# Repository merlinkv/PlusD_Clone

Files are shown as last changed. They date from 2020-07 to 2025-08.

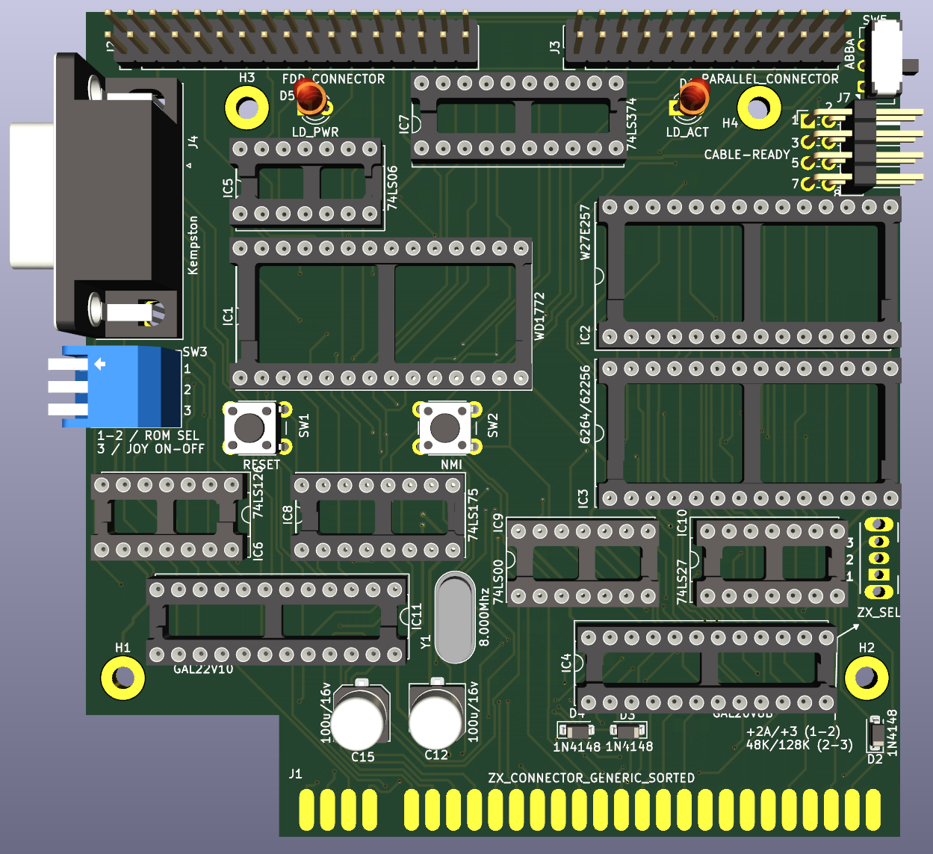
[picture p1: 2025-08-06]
ZX_PlusD_Clone_1_7_Front.jpg

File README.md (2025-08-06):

# PlusD Clone

<br />This work is licensed under a <a rel="license" href="http://creativecommons.org/licenses/by-nc-sa/4.0/">Creative Commons Attribution-NonCommercial-ShareAlike 4.0 International License</a>.

* If you remix, transform, or build upon the material, you must distribute your contributions under the same license as the original.
* You may not use the material for commercial purposes.
* You must give appropriate credit, provide a link to the license, and indicate if changes were made. You may do so in any reasonable manner, but not in any way that suggests the licensor endorses you or your use.

This interface is based on the original PlusD (+D) interface from Miles Gordon Technology and the clone designs by @Pachuquin & @alvaroalea.

# ATTENTION

This project was made for the retro community and not for commercial purposes. So only retro hardware forums and individual people can build this project.

THE SALE OF ANY PART OF THIS PROJECT ON EBAY OR OTHER AUCTION SITES IS PROHIBITED

# Note

I take no responsibiltiy for any damage to any equipment that results from the use of this board. USE AT YOUR OWN RISK!

# Original short description

The PlusD (or +D) was a floppy disk and printer interface for the Sinclair ZX Spectrum home computer, developed as a successor to Miles Gordon Technology's earlier product, the DISCiPLE. It runs the GDOS or Uni-Dos operating systems and you can connect up to two 3.5" floppy drives.

The PlusD will allow you to save all your games and serious software to disc at the touch of a button for reloading at any time in the future. With the fastest load and
save times of any disc system available for the Spectrum, the PLUS D will make your computer grow to meet your needs today and tomorrow! In the software arena, many
leading companies are now producing software that is specifically tailored to the PLUS D. But don't worry - you don't have to buy new software to use the PLUS D!
And if some of your software is Microdrive compatible, so much the better! The PLUS D will add a new dimension to all your existing software, greatly enhancing all
your own programs as well!

# August 6, 2025 - PlusD Clone 1.7

* Added Fire2 button on Kempston interface. Now you can play games that are ready for two buttons or modified to add this possibility like on some games modded by @mad3001 at the VDR site: [Games with Fire2](https://www.va-de-retro.com/foros/viewtopic.php?t=12277)

- [Interactive BOM](https://htmlpreview.github.io/?https://github.com/merlinkv/PlusD_Clone/blob/master/ZX_PlusD_Clone_1_7.html)

# PlusD Clone 1.6

My ZX PlusD Clone can be used on all ZX Spectrum computers just using a little switch (you don't need a "fixer" for +2A, +2B or +3 models). Also you can select one of the two ROMs included (GDOS & Uni-Dos -up to four ROMs can be used-) and play almost all games with the integrated Kempston Joystick interface.

# July 30, 2021

* Corrected some IC labels on the board.

# November 25, 2020

* The solder pad used to select the floppy drive controller IC has been removed.
The floppy drive controller IC's that can be used are: WD1772-02-00, WD1772-02-02 & VL1772-02PC
* Some minor changes.

# October 16, 2020

* Resistors, capacitors (except the two electrolytics) & diodes now are SMD 1206
* Some minor changes

# September 25, 2020

* In this version the solder pads to select the READY signal has been removed.
* Now you can fin a connector of 4x2 pins to put the jumpers.
     
     * Upper row: Cable selector (AT or Shugart)
     * Bottom row: READY signal selector, REAL or EMU
      
     See attached pictures.

# July 27, 2020

Tested & working 100%
* In this version of the board the IC 7805 has been removed. The interface power is taken from the + 5V line of the expansion bus.

# July 11, 2020

* Corrected footprint of U2 (W27E257)
* Everything seems to be OK. Ordering 5 PCB's to test.

# July 6, 2020

* Added a SPDT switch ON-ON to select between ZX 48K/128K & +2A/+3
* Inversion of Drive 1 and Drive 2 now is made by a DPDT Switch (ABBA)
* Now the IC12 (L7805) can be placed horizontally
* Relocation of LEDS, NMI and RESET pushbuttons and some IC's
* Added three 3M holes (3.5mm) to facilitate the fixation on a case
* Kempston Joystick connector now is horizontal
* Changed the DIP switch for ROM selection and Joystick ON-OFF for a DIP Switch Piano style.
* Electrolytic capacitors are now SMD

# Notes

Two types can be used as the IC for floppy disk controller: WD1772 (versions 02-00 and 02-02) and VL1772-02PC.
Unfortunately, they are difficult to find at reasonable prices.

The advantages of this interface over the original are:

* 4 Banks of ROM, so you can swap between G+Dos and Unidos, selectable by dip-switches
* Included Fixed for +2A/+3, so can be used in any ZX Spectrum, selection by switch
* Kempston Joystick Interface included, can be disable by dip-switch
* Reset Button
* Posibility of use crossed or plain floppy cable, and invert Drive 1 and Drive 2, very usefull if you have a Gotek and a real floppy.

# Links

* https://www.winuaespanol.com/phpbb3/viewtopic.php?p=7182#p7182
* https://github.com/alvaroalea/plusD-clone
* https://www.va-de-retro.com/foros/viewtopic.php?f=63&t=5561

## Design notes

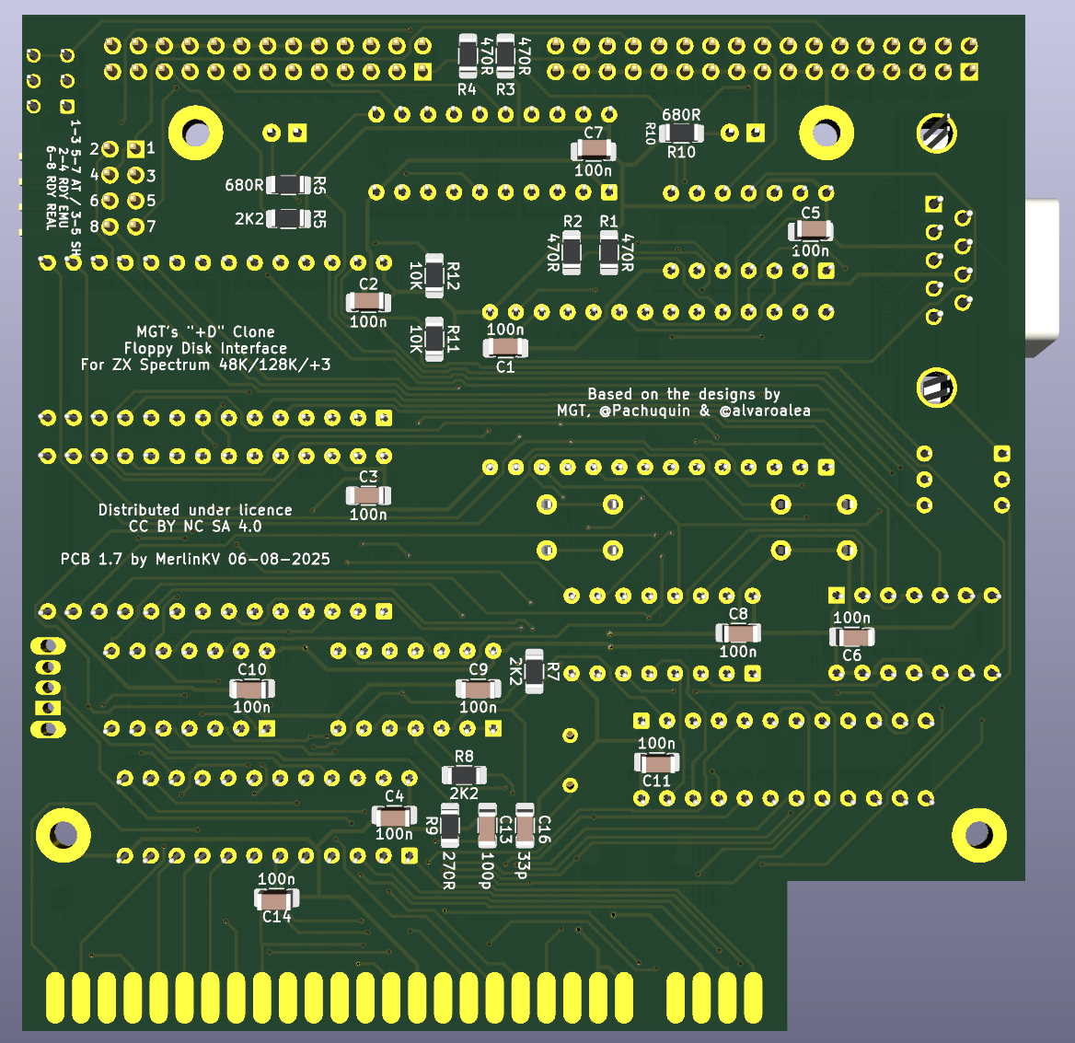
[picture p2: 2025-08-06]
ZX_PlusD_Clone_1_7_Back.jpg

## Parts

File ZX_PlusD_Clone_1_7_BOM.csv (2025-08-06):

Id | Designator | Footprint | Quantity | Designation | Supplier and ref
1 | J4 | DSUB-9_Male_Horizontal_P2.77x2.84mm_EdgePinOffset4.94mm_Housed_MountingHolesOffset7.48mm | 1 | Kempston
2 | SW4 | SW_CuK_OS102011MA1QN1_SPDT_Angled | 1 | ZX_SEL
3 | IC10 | DIP-14_W7.62mm_Socket | 1 | 74LS27
4 | IC9 | DIP-14_W7.62mm_Socket | 1 | 74LS00
5 | IC6 | DIP-14_W7.62mm_Socket | 1 | 74LS126
6 | D5 | LED_D3.0mm | 1 | LD_PWR
7 | SW3 | SW_DIP_SPSTx03_Piano_10.8x9.18mm_W7.62mm_P2.54mm | 1 | ROMSEL_JOY
8 | Y1 | Crystal_HC18-U_Vertical | 1 | 8.000Mhz
9 | D1 | LED_D3.0mm | 1 | LD_ACT
10 | IC5 | DIP-14_W7.62mm_Socket | 1 | 74LS06
11 | J3 | PinHeader_2x13_P2.54mm_Vertical | 1 | PARALLEL_CONNECTOR
12 | J1 | ZX_CONNECTOR_GENERIC_SORTED | 1 | ZX_CONNECTOR_GENERIC_SORTED
13 | IC1 | DIP-28_W15.24mm_Socket | 1 | WD1772
14 | IC3 | DIP-28_W15.24mm_Socket | 1 | 6264/62256
15 | IC4 | DIP-24_W7.62mm_Socket | 1 | GAL20V8B
16 | IC8 | DIP-16_W7.62mm_Socket | 1 | 74LS175
17 | IC7 | DIP-20_W7.62mm_Socket | 1 | 74LS374
18 | SW1 | SW_PUSH_6mm | 1 | RESET
19 | SW2 | SW_PUSH_6mm | 1 | NMI
20 | IC11 | DIP-24_W7.62mm_Socket | 1 | GAL22V10
21 | IC2 | DIP-28_W15.24mm_Socket | 1 | W27E257
22 | SW5 | SW_CK_JS202011AQN_DPDT_Angled | 1 | ABBA
23 | C15,C12 | C_Elec_6.3x5.4 | 2 | 100u/16v
24 | J7 | PinHeader_2x04_P2.54mm_Horizontal | 1 | CABLE-READY
25 | D2,D3,D4 | D_SOD-123 | 3 | 1N4148
26 | J2 | PinHeader_2x17_P2.54mm_Vertical | 1 | FDD_CONNECTOR
27 | C16 | C_1206_3216Metric_Pad1.33x1.80mm_HandSolder | 1 | 33p
28 | R9 | R_1206_3216Metric_Pad1.30x1.75mm_HandSolder | 1 | 270R
29 | R6,R10 | R_1206_3216Metric_Pad1.30x1.75mm_HandSolder | 2 | 680R
30 | R12,R11 | R_1206_3216Metric_Pad1.30x1.75mm_HandSolder | 2 | 10K
31 | R7,R8,R5 | R_1206_3216Metric_Pad1.30x1.75mm_HandSolder | 3 | 2K2
32 | C13 | C_1206_3216Metric_Pad1.33x1.80mm_HandSolder | 1 | 100p
33 | C14,C1,C4,C5,C6,C7,C8,C9,C10,C11,C2,C3 | C_1206_3216Metric_Pad1.33x1.80mm_HandSolder | 12 | 100n
34 | R1,R2,R4,R3 | R_1206_3216Metric_Pad1.30x1.75mm_HandSolder | 4 | 470R

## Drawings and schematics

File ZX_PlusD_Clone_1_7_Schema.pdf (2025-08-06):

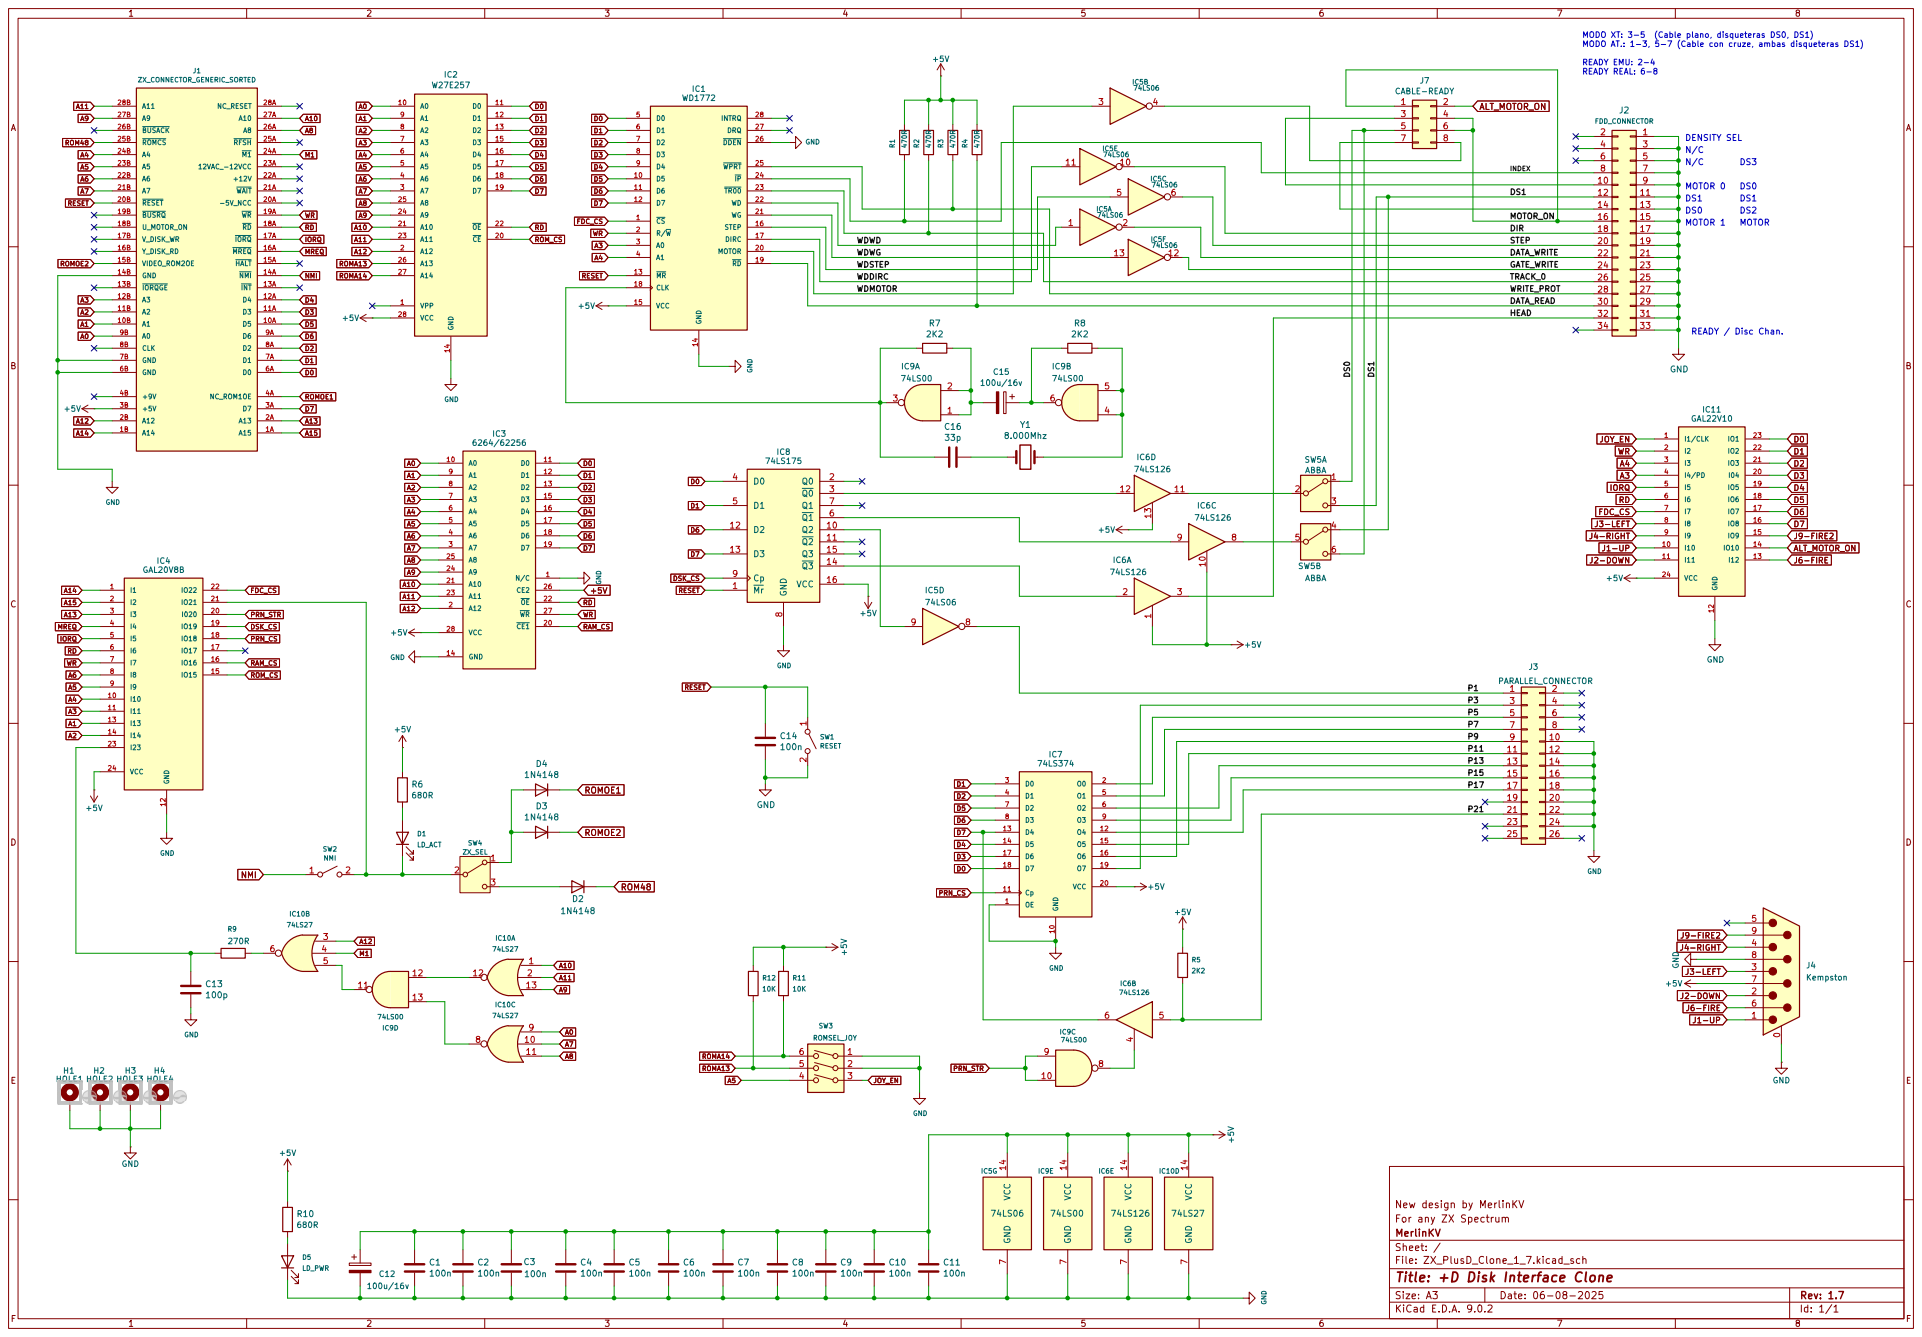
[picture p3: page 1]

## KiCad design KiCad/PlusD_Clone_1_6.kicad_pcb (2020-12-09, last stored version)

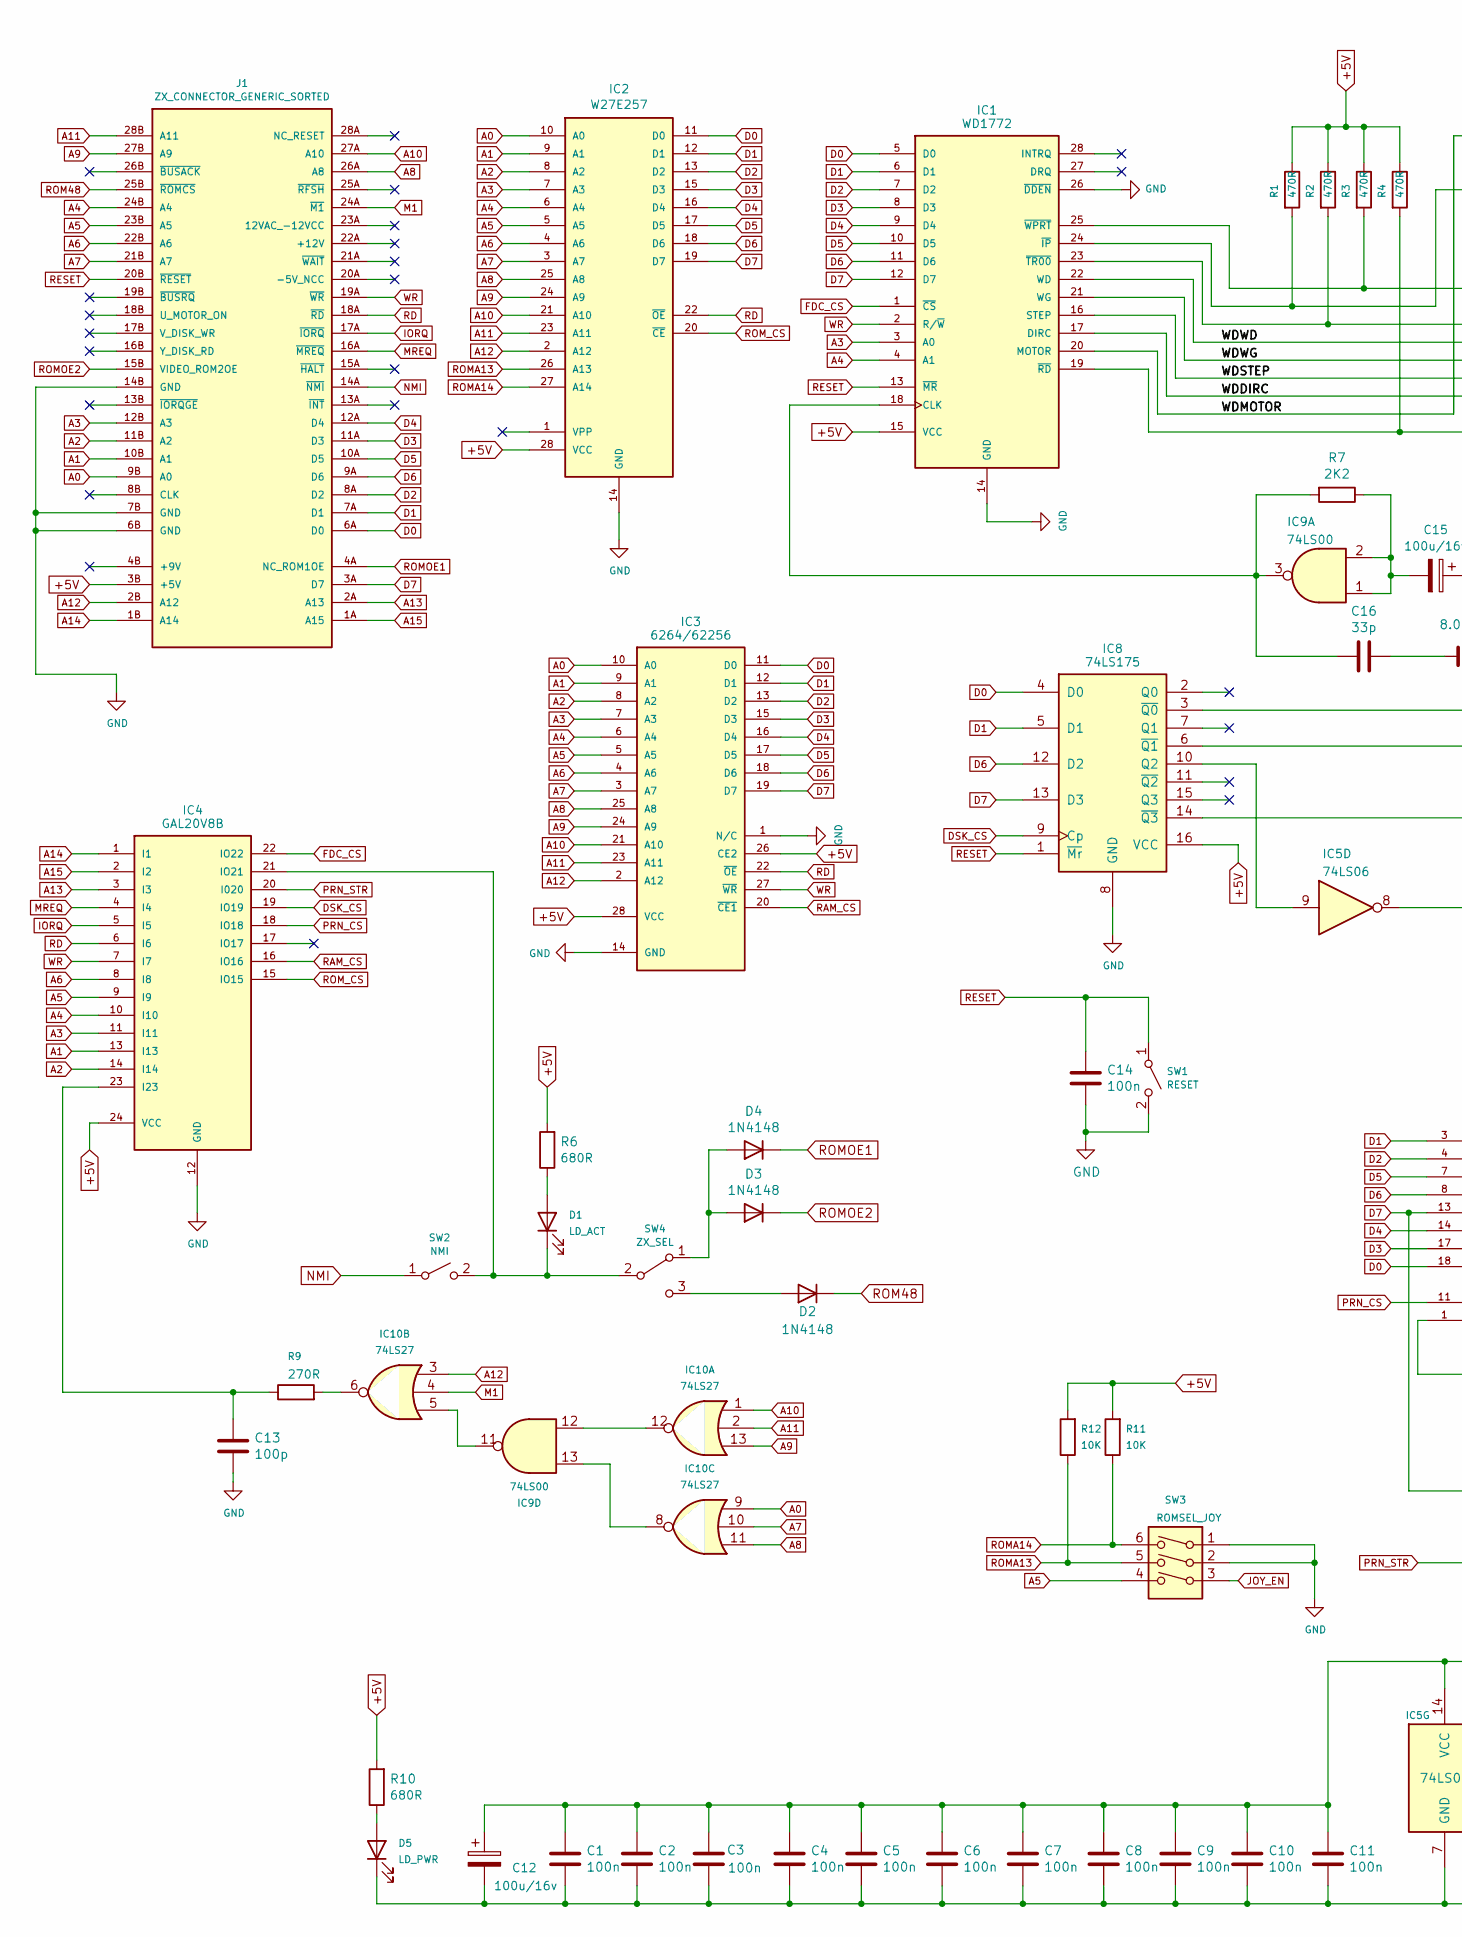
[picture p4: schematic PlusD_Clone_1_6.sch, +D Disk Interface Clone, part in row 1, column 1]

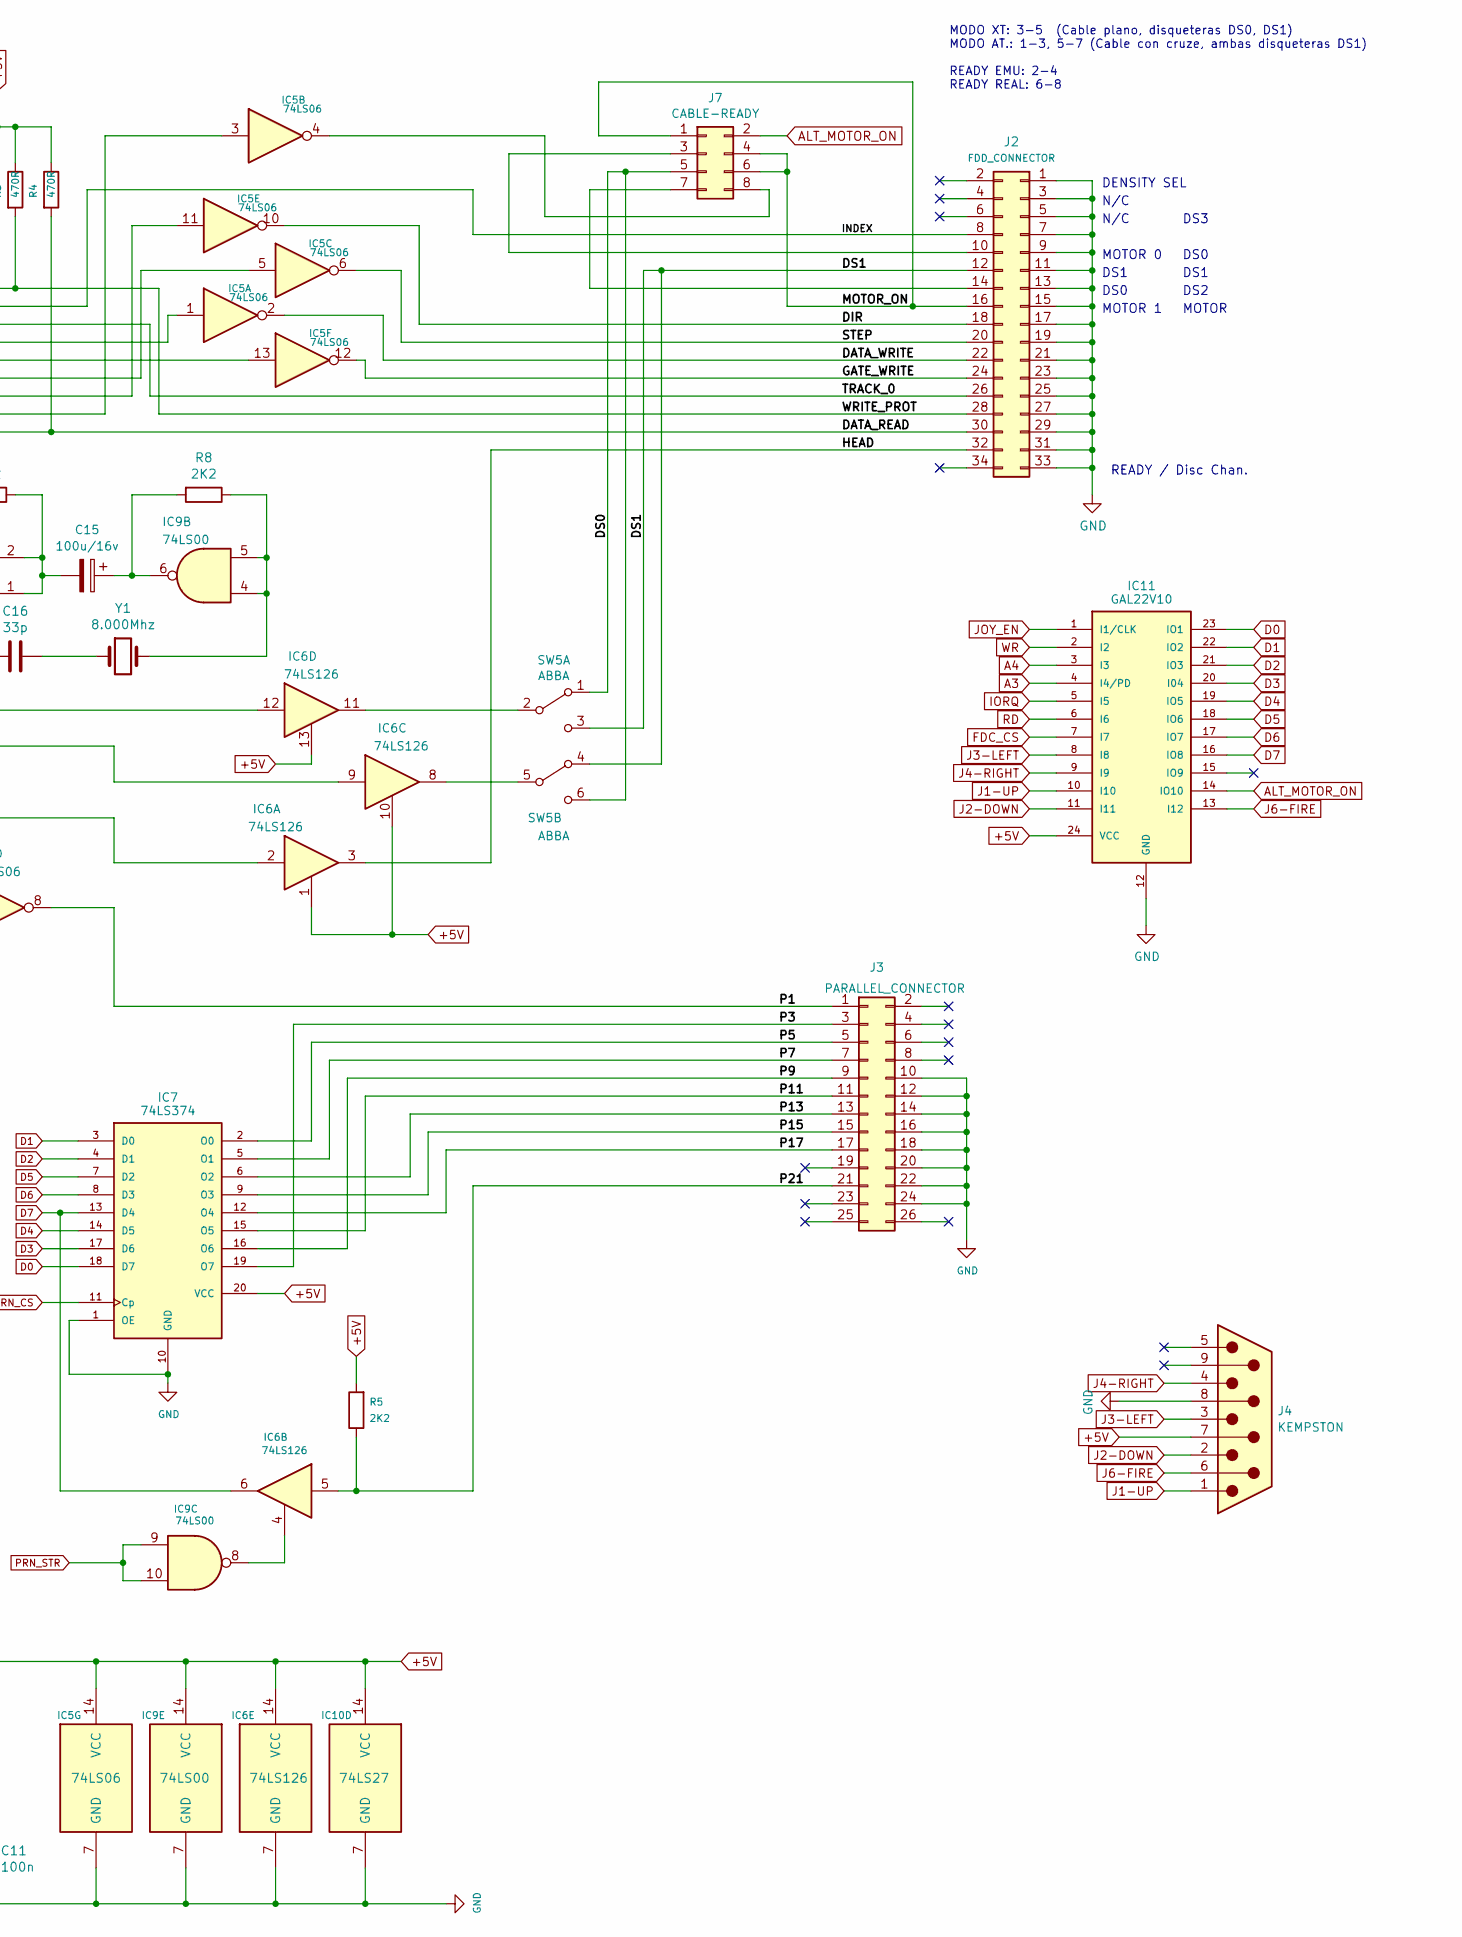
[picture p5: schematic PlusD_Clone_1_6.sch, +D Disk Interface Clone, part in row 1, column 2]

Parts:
C1, C2, C3, C4, C5, C6, C7, C8, C9, C10, C11, C14: 100n; C_1206_3216Metric_Pad1.42x1.75mm_HandSolder
C12, C15: 100u/16v; C_Elec_6.3x5.4
C13: 100p; C_1206_3216Metric_Pad1.42x1.75mm_HandSolder
C16: 33p; C_1206_3216Metric_Pad1.42x1.75mm_HandSolder
D1: LD_ACT; LED_D5.0mm
D2, D3, D4: 1N4148; D_SOD-123
D5: LD_PWR; LED_D5.0mm
IC1: WD1772; DIP-28_W15.24mm_Socket_LongPads
IC2: W27E257; DIP-28_W15.24mm_Socket_LongPads
IC3: 6264/62256; DIP-28_W15.24mm_Socket_LongPads
IC4: GAL20V8B; DIP-24_W7.62mm_Socket_LongPads
IC5: 74LS06; DIP-14_W7.62mm_Socket_LongPads
IC6: 74LS126; DIP-14_W7.62mm_Socket_LongPads
IC7: 74LS374; DIP-20_W7.62mm_Socket_LongPads
IC8: 74LS175; DIP-16_W7.62mm_Socket_LongPads
IC9: 74LS00; DIP-14_W7.62mm_Socket_LongPads
IC10: 74LS27; DIP-14_W7.62mm_Socket_LongPads
IC11: GAL22V10; DIP-24_W7.62mm_Socket_LongPads
J1: ZX_CONNECTOR_GENERIC_SORTED
J2: FDD_CONNECTOR; PinHeader_2x17_P2.54mm_Vertical
J3: PARALLEL_CONNECTOR; PinHeader_2x13_P2.54mm_Vertical
J4: KEMPSTON; DSUB-9_Male_Horizontal_P2.77x2.84mm_EdgePinOffset4.94mm_Hou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
J7: CABLE-READY; PinHeader_2x04_P2.54mm_Horizontal
R1, R2, R3, R4: 470R; R_1206_3216Metric_Pad1.42x1.75mm_HandSolder
R5, R7, R8: 2K2; R_1206_3216Metric_Pad1.42x1.75mm_HandSolder
R6, R10: 680R; R_1206_3216Metric_Pad1.42x1.75mm_HandSolder
R9: 270R; R_1206_3216Metric_Pad1.42x1.75mm_HandSolder
R11, R12: 10K; R_1206_3216Metric_Pad1.42x1.75mm_HandSolder
SW1: RESET; SW_PUSH_6mm
SW2: NMI; SW_PUSH_6mm
SW3: ROMSEL_JOY; SW_DIP_SPSTx03_Piano_10.8x9.18mm_W7.62mm_P2.54mm
SW4: ZX_SEL; SW_CuK_OS102011MA1QN1_SPDT_Angled
SW5: ABBA; SW_CuK_JS202011AQN_DPDT_Angled
Y1: 8.000Mhz; Crystal_HC18-U_Vertical

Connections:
+5V: C1.2, C2.2, C3.2, C4.2, C5.2, C6.2, C7.2, C8.2, C9.2, C10.2, C11.2, C12.1, IC1.15 (VCC), IC2.28 (VCC), IC3.26 (CE2), IC3.28 (VCC), IC4.24 (VCC), IC5.14 (VCC), IC6.1, IC6.10, IC6.13, IC6.14 (VCC), IC7.20 (VCC), IC8.16 (VCC), IC9.14 (VCC), IC10.14 (VCC), IC11.24 (VCC), J1.3B (+5V), J4.7, R1.1, R2.1, R3.1, R4.1, R5.2, R6.2, R10.2, R11.2, R12.2
/DATA_READ: IC1.19 (~RD), J2.30, R4.2
/DATA_WRITE: IC5.2, J2.22
/DIR: IC5.10, J2.18
/DS0: J7.5, SW5.1 (A), SW5.6 (C)
/DS1: J2.12, SW5.3 (C), SW5.4 (A)
/GATE_WRITE: IC5.12, J2.24
/HEAD: IC6.3, J2.32
/INDEX: IC1.24 (~IP), J2.8, R1.2
/MOTOR_ON: J2.16, J7.1, J7.4, J7.6
/P1: IC5.8, J3.1
/P3: IC7.19 (O7), J3.3
/P5: IC7.2 (O0), J3.5
/P7: IC7.5 (O1), J3.7
/P9: IC7.16 (O6), J3.9
/P11: IC7.15 (O5), J3.11
/P13: IC7.6 (O2), J3.13
/P15: IC7.9 (O3), J3.15
/P17: IC7.12 (O4), J3.17
/P21: IC6.5, J3.21, R5.1
/STEP: IC5.6, J2.20
/TRACK_0: IC1.23 (~TR00), J2.26, R2.2
/WDDIRC: IC1.17 (DIRC), IC5.11
/WDMOTOR: IC1.20 (MOTOR), IC5.3
/WDSTEP: IC1.16 (STEP), IC5.5
/WDWD: IC1.22 (WD), IC5.1
/WDWG: IC1.21 (WG), IC5.13
/WRITE_PROT: IC1.25 (~WPRT), J2.28, R3.2
A0: IC2.10 (A0), IC3.10 (A0), IC10.9, J1.9B (A0)
A1: IC2.9 (A1), IC3.9 (A1), IC4.13 (I13), J1.10B (A1)
A2: IC2.8 (A2), IC3.8 (A2), IC4.14 (I14), J1.11B (A2)
A3: IC1.3 (A0), IC2.7 (A3), IC3.7 (A3), IC4.11 (I11), IC11.4 (I4/PD), J1.12B (A3)
A4: IC1.4 (A1), IC2.6 (A4), IC3.6 (A4), IC4.10 (I10), IC11.3 (I3), J1.24B (A4)
A5: IC2.5 (A5), IC3.5 (A5), IC4.9 (I9), J1.23B (A5), SW3.4
A6: IC2.4 (A6), IC3.4 (A6), IC4.8 (I8), J1.22B (A6)
A7: IC2.3 (A7), IC3.3 (A7), IC10.10, J1.21B (A7)
A8: IC2.25 (A8), IC3.25 (A8), IC10.11, J1.26A (A8)
A9: IC2.24 (A9), IC3.24 (A9), IC10.13, J1.27B (A9)
A10: IC2.21 (A10), IC3.21 (A10), IC10.1, J1.27A (A10)
A11: IC2.23 (A11), IC3.23 (A11), IC10.2, J1.28B (A11)
A12: IC2.2 (A12), IC3.2 (A12), IC10.3, J1.2B (A12)
A13: IC4.3 (I3), J1.2A (A13)
A14: IC4.1 (I1), J1.1B (A14)
A15: IC4.2 (I2), J1.1A (A15)
ALT_MOTOR_ON: IC11.14 (IO10), J7.2
D0: IC1.5 (D0), IC2.11 (D0), IC3.11 (D0), IC7.18 (D7), IC8.4 (D0), IC11.23 (IO1), J1.6A (D0)
D1: IC1.6 (D1), IC2.12 (D1), IC3.12 (D1), IC7.3 (D0), IC8.5 (D1), IC11.22 (IO2), J1.7A (D1)
D2: IC1.7 (D2), IC2.13 (D2), IC3.13 (D2), IC7.4 (D1), IC11.21 (IO3), J1.8A (D2)
D3: IC1.8 (D3), IC2.15 (D3), IC3.15 (D3), IC7.17 (D6), IC11.20 (I04), J1.11A (D3)
D4: IC1.9 (D4), IC2.16 (D4), IC3.16 (D4), IC7.14 (D5), IC11.19 (IO5), J1.12A (D4)
D5: IC1.10 (D5), IC2.17 (D5), IC3.17 (D5), IC7.7 (D2), IC11.18 (IO6), J1.10A (D5)
D6: IC1.11 (D6), IC2.18 (D6), IC3.18 (D6), IC7.8 (D3), IC8.12 (D2), IC11.17 (IO7), J1.9A (D6)
D7: IC1.12 (D7), IC2.19 (D7), IC3.19 (D7), IC6.6, IC7.13 (D4), IC8.13 (D3), IC11.16 (IO8), J1.3A (D7)
DSK_CS: IC4.19 (IO19), IC8.9 (Cp)
FDC_CS: IC1.1 (~CS), IC4.22 (IO22), IC11.7 (I7)
GND: C1.1, C2.1, C3.1, C4.1, C5.1, C6.1, C7.1, C8.1, C9.1, C10.1, C11.1, C12.2, C13.1, C14.1, D5.1 (K), IC1.14 (GND), IC1.26 (~DDEN), IC2.14 (GND), IC3.1 (N/C), IC3.14 (GND), IC4.12 (GND), IC5.7 (GND), IC6.7 (GND), IC7.1 (OE), IC7.10 (GND), IC8.8 (GND), IC9.7 (GND), IC10.7 (GND), IC11.12 (GND), J1.6B (GND), J1.7B (GND), J1.14B (GND), J2.1, J2.3, J2.5, J2.7, J2.9, J2.11, J2.13, J2.15, J2.17, J2.19, J2.21, J2.23, J2.25, J2.27, J2.29, J2.31, J2.33, J3.10, J3.12, J3.14, J3.16, J3.18, J3.20, J3.22, J3.24, J4.8, SW1.2 (B), SW3.1, SW3.2
IORQ: IC4.5 (I5), IC11.5 (I5), J1.17A (~IORQ)
J1-UP: IC11.10 (I10), J4.1
J2-DOWN: IC11.11 (I11), J4.2
J3-LEFT: IC11.8 (I8), J4.3
J4-RIGHT: IC11.9 (I9), J4.4
J6-FIRE: IC11.13 (I12), J4.6
JOY_EN: IC11.1 (I1/CLK), SW3.3
M1: IC10.4, J1.24A (~M1)
MREQ: IC4.4 (I4), J1.16A (~MREQ)
NMI: J1.14A (~NMI), SW2.1 (A)
unnamed: C13.2, IC4.23 (I23), R9.1
unnamed: C15.1, IC9.6, R8.2
unnamed: C15.2, IC9.1, IC9.2, R7.1
unnamed: C16.1, Y1.1
unnamed: C16.2, IC1.18 (CLK), IC9.3, R7.2
unnamed: D1.1 (K), IC4.21 (IO21), SW2.2 (B), SW4.2 (B)
unnamed: D1.2 (A), R6.1
unnamed: D2.2 (A), SW4.3 (C)
unnamed: D3.2 (A), D4.2 (A), SW4.1 (A)
unnamed: D5.2 (A), R10.1
unnamed: IC5.4, J7.8
unnamed: IC5.9, IC8.10 (Q2)
unnamed: IC6.2, IC8.14 (~Q3)
unnamed: IC6.4, IC9.8
unnamed: IC6.8, SW5.5 (B)
unnamed: IC6.9, IC8.6 (~Q1)
unnamed: IC6.11, SW5.2 (B)
unnamed: IC6.12, IC8.3 (~Q0)
unnamed: IC9.4, IC9.5, R8.1, Y1.2
unnamed: IC9.11, IC10.5
unnamed: IC10.6, R9.2
unnamed: IC9.13, IC10.8
unnamed: IC9.12, IC10.12
unnamed: J2.10, J7.3
unnamed: J2.14, J7.7
PRN_CS: IC4.18 (IO18), IC7.11 (Cp)
PRN_STR: IC4.20 (I020), IC9.9, IC9.10
RAM_CS: IC3.20 (~CE1), IC4.16 (IO16)
RD: IC2.22 (~OE), IC3.22 (~OE), IC4.6 (I6), IC11.6 (I6), J1.18A (~RD)
RESET: C14.2, IC1.13 (~MR), IC8.1 (~Mr), J1.20B (~RESET), SW1.1 (A)
ROM48: D2.1 (K), J1.25B (~ROMCS)
ROMA13: IC2.26 (A13), R12.1, SW3.5
ROMA14: IC2.27 (A14), R11.1, SW3.6
ROMOE1: D4.1 (K), J1.4A (NC_ROM1OE)
ROMOE2: D3.1 (K), J1.15B (VIDEO_ROM2OE)
ROM_CS: IC2.20 (~CE), IC4.15 (IO15)
WR: IC1.2 (R/~W), IC3.27 (~WR), IC4.7 (I7), IC11.2 (I2), J1.19A (~WR)

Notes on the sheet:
READY / Disc Chan.
DENSITY SEL
N/C
MOTOR 1
DS0
DS1
MOTOR 0
MOTOR
DS2
DS0
DS3
MODO XT: 3-5 (Cable plano, disqueteras DS0, DS1) MODO AT.: 1-3, 5-7 (Cable con cruze, ambas disqueteras DS1) READY EMU: 2-4 READY REAL: 6-8

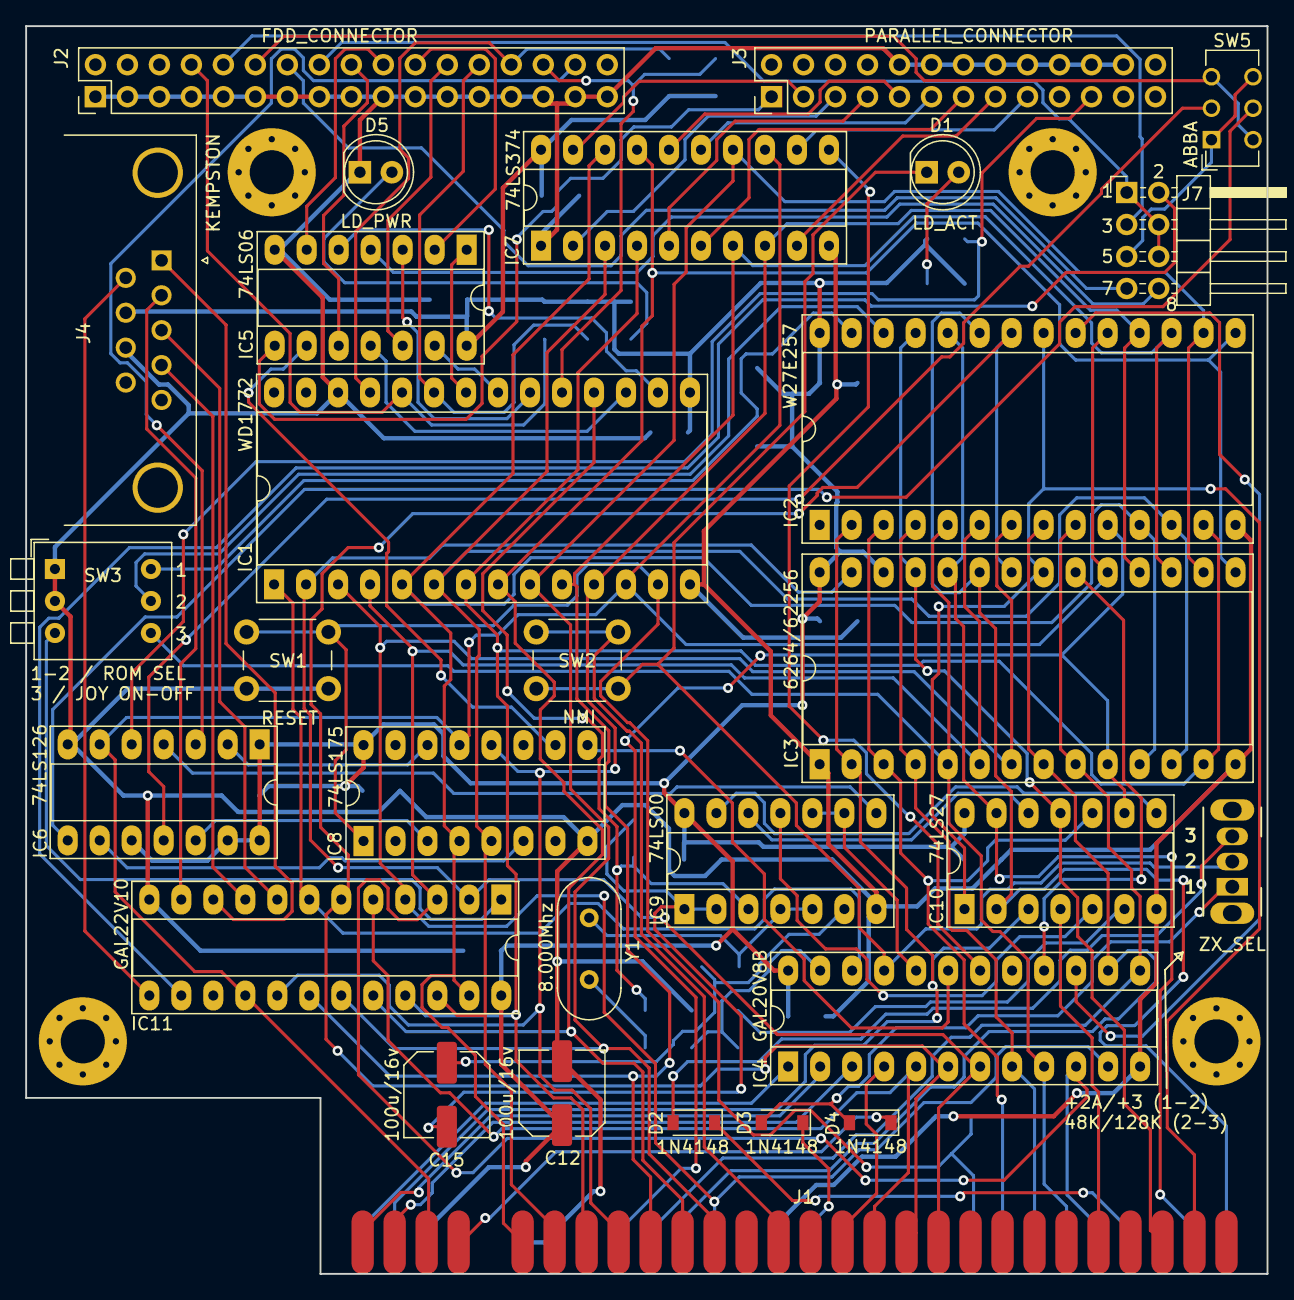
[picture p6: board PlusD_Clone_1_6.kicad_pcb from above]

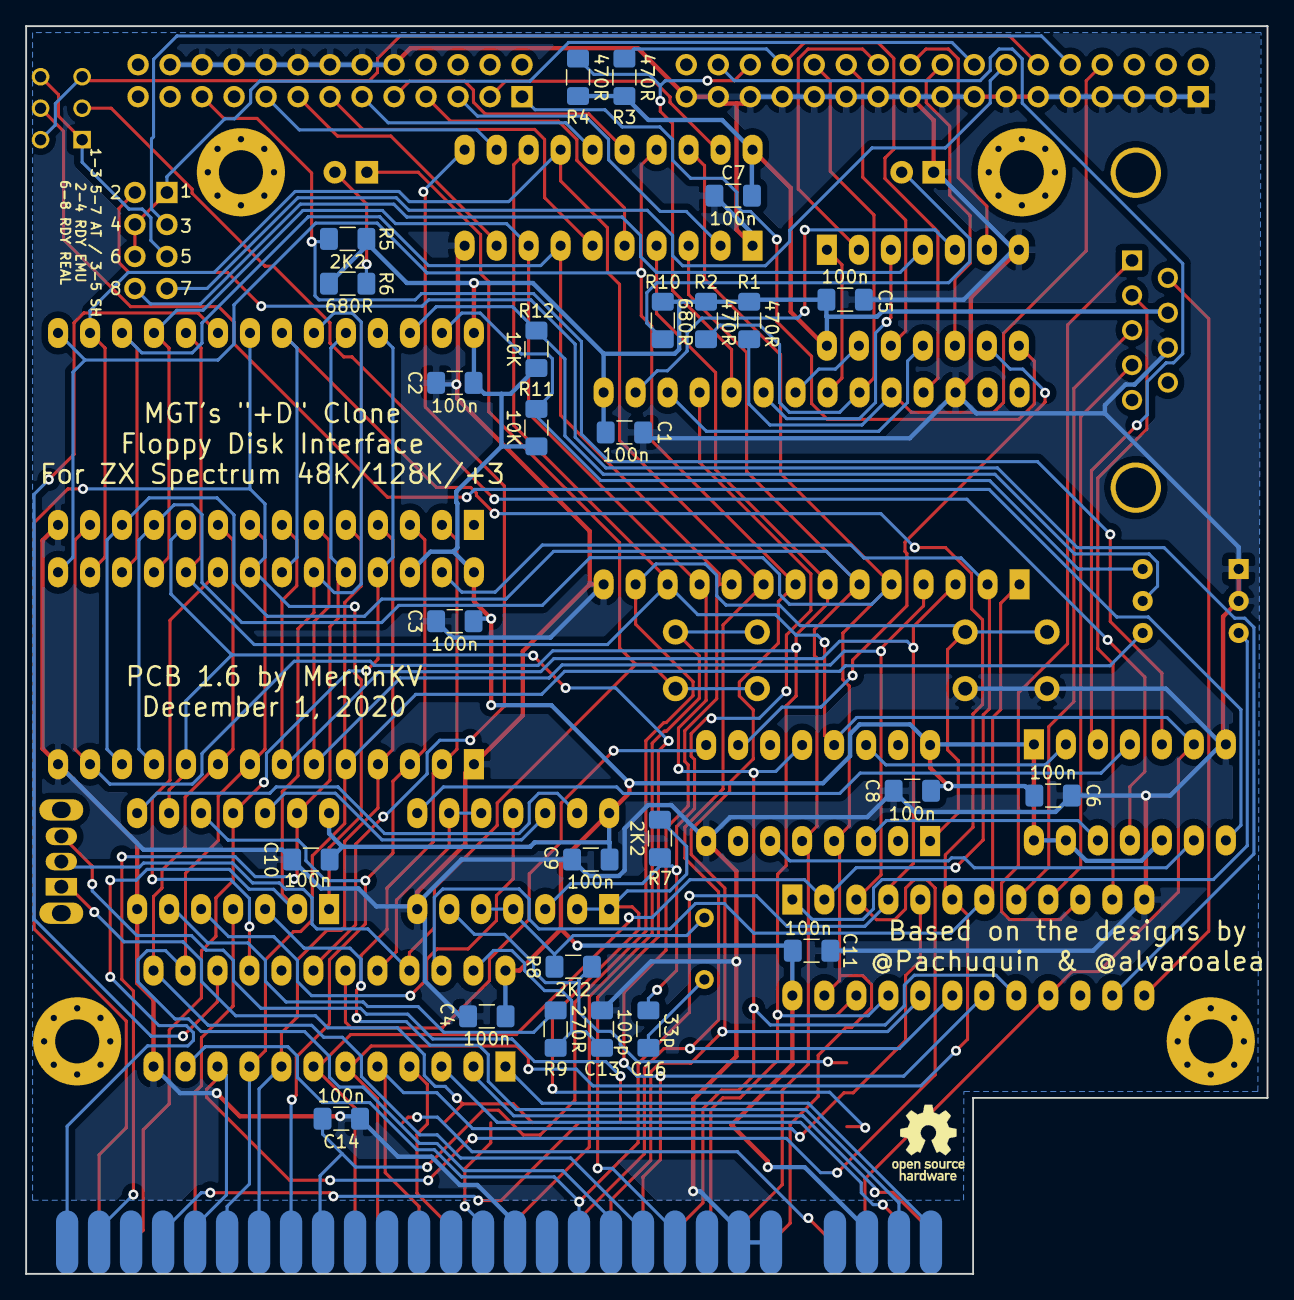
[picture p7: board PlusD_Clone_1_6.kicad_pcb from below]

Board: 2 copper layers, 98.6 x 99.1 mm, 60 parts (27 on the bottom side), 103 nets.

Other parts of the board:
HOLE1, HOLE2, HOLE3, HOLE4: MountingHole_3.5mm_Pad_Via
LOGO1: OSHW-Logo_5.7x6mm_SilkScreen

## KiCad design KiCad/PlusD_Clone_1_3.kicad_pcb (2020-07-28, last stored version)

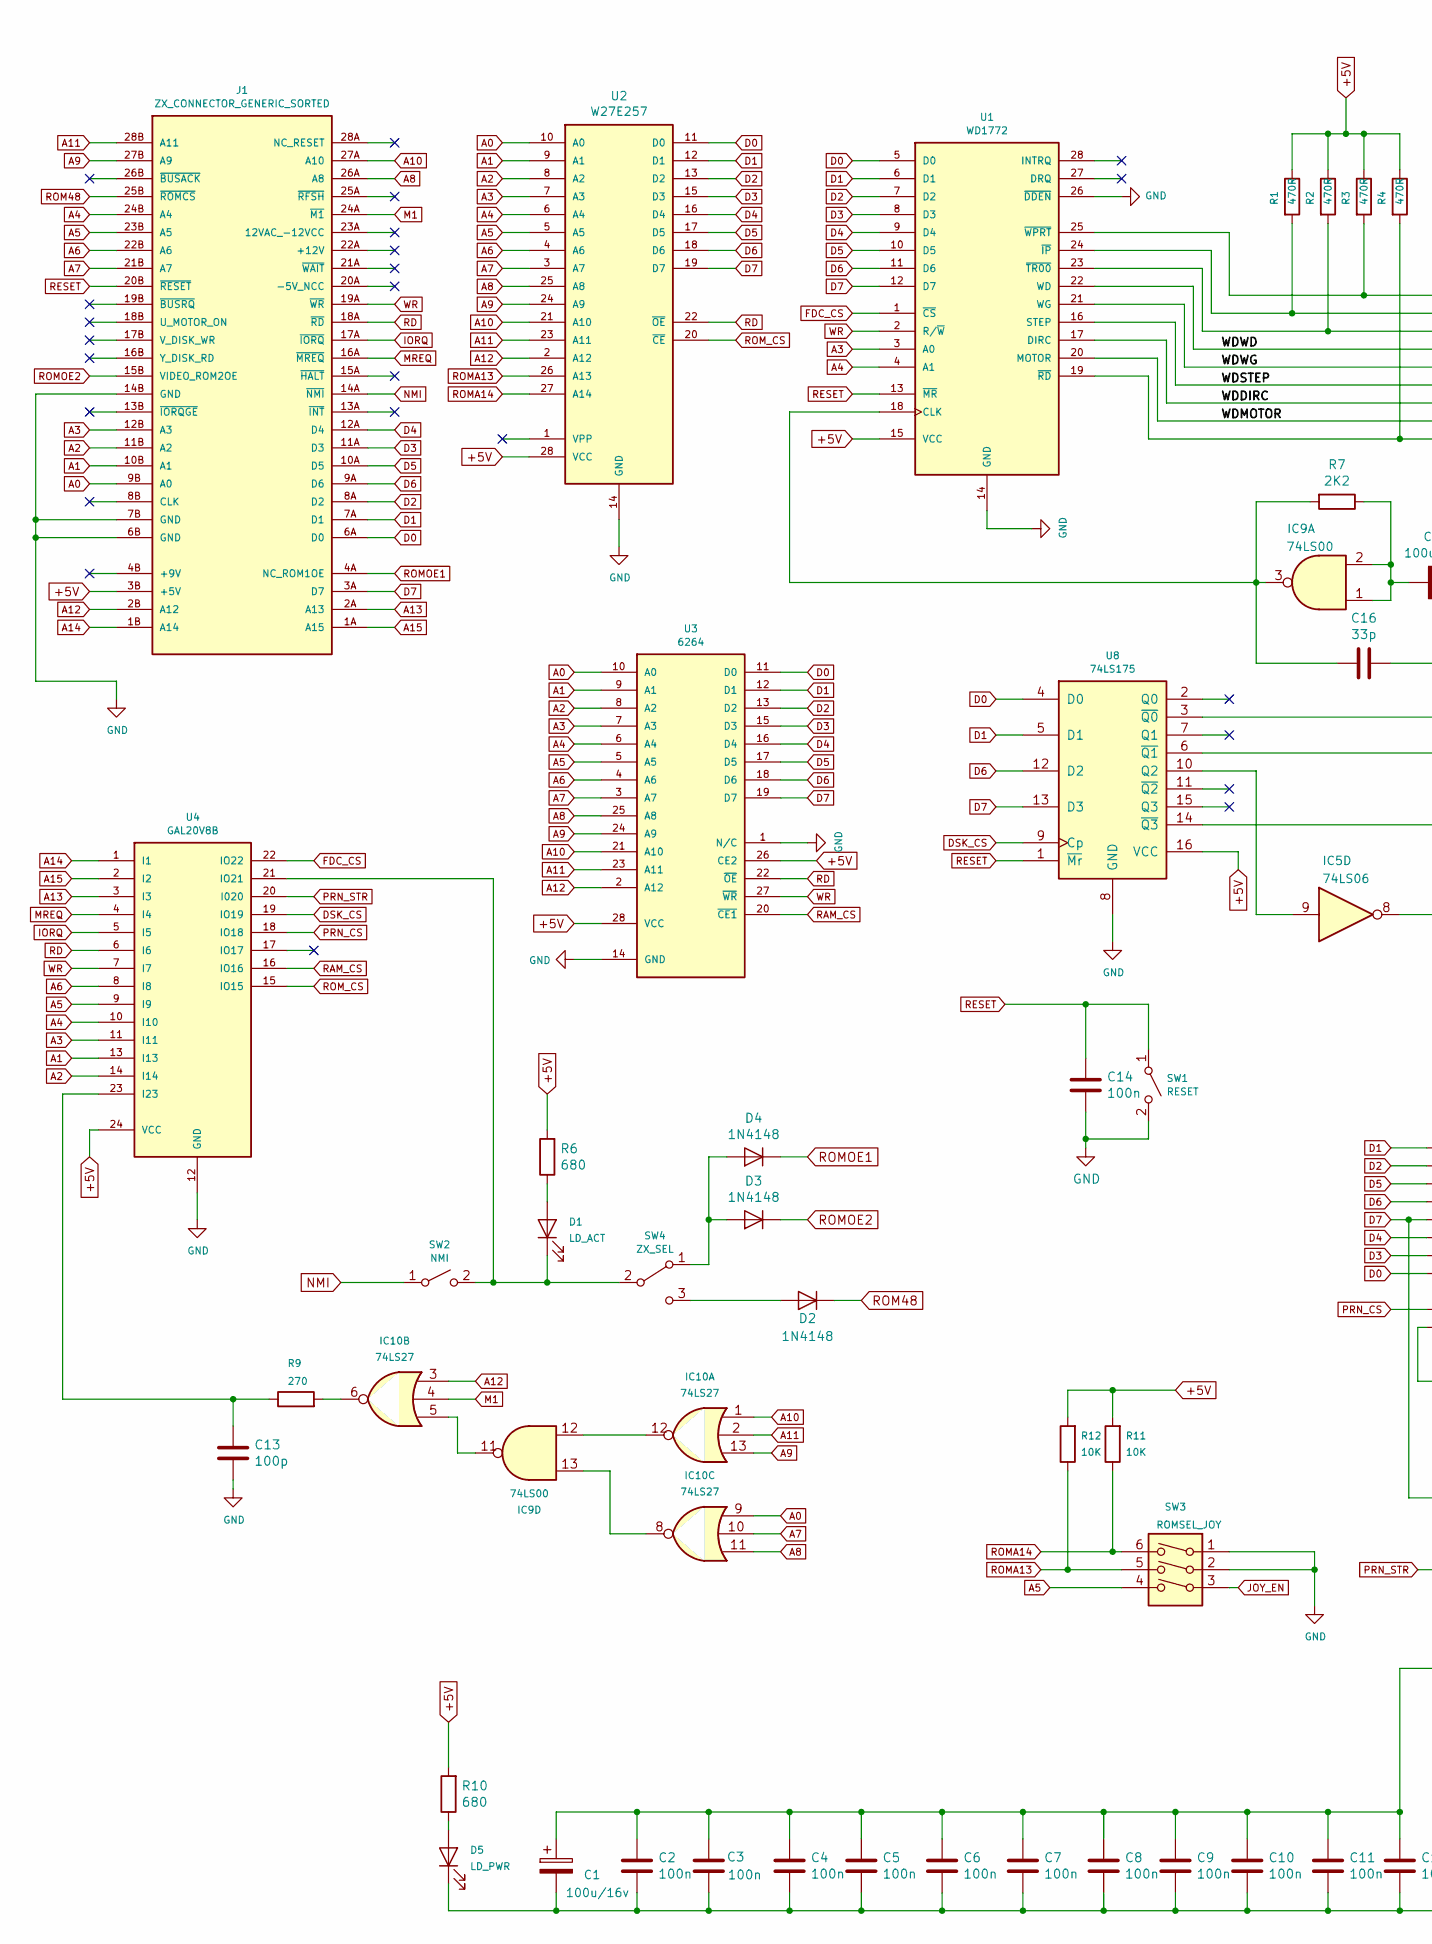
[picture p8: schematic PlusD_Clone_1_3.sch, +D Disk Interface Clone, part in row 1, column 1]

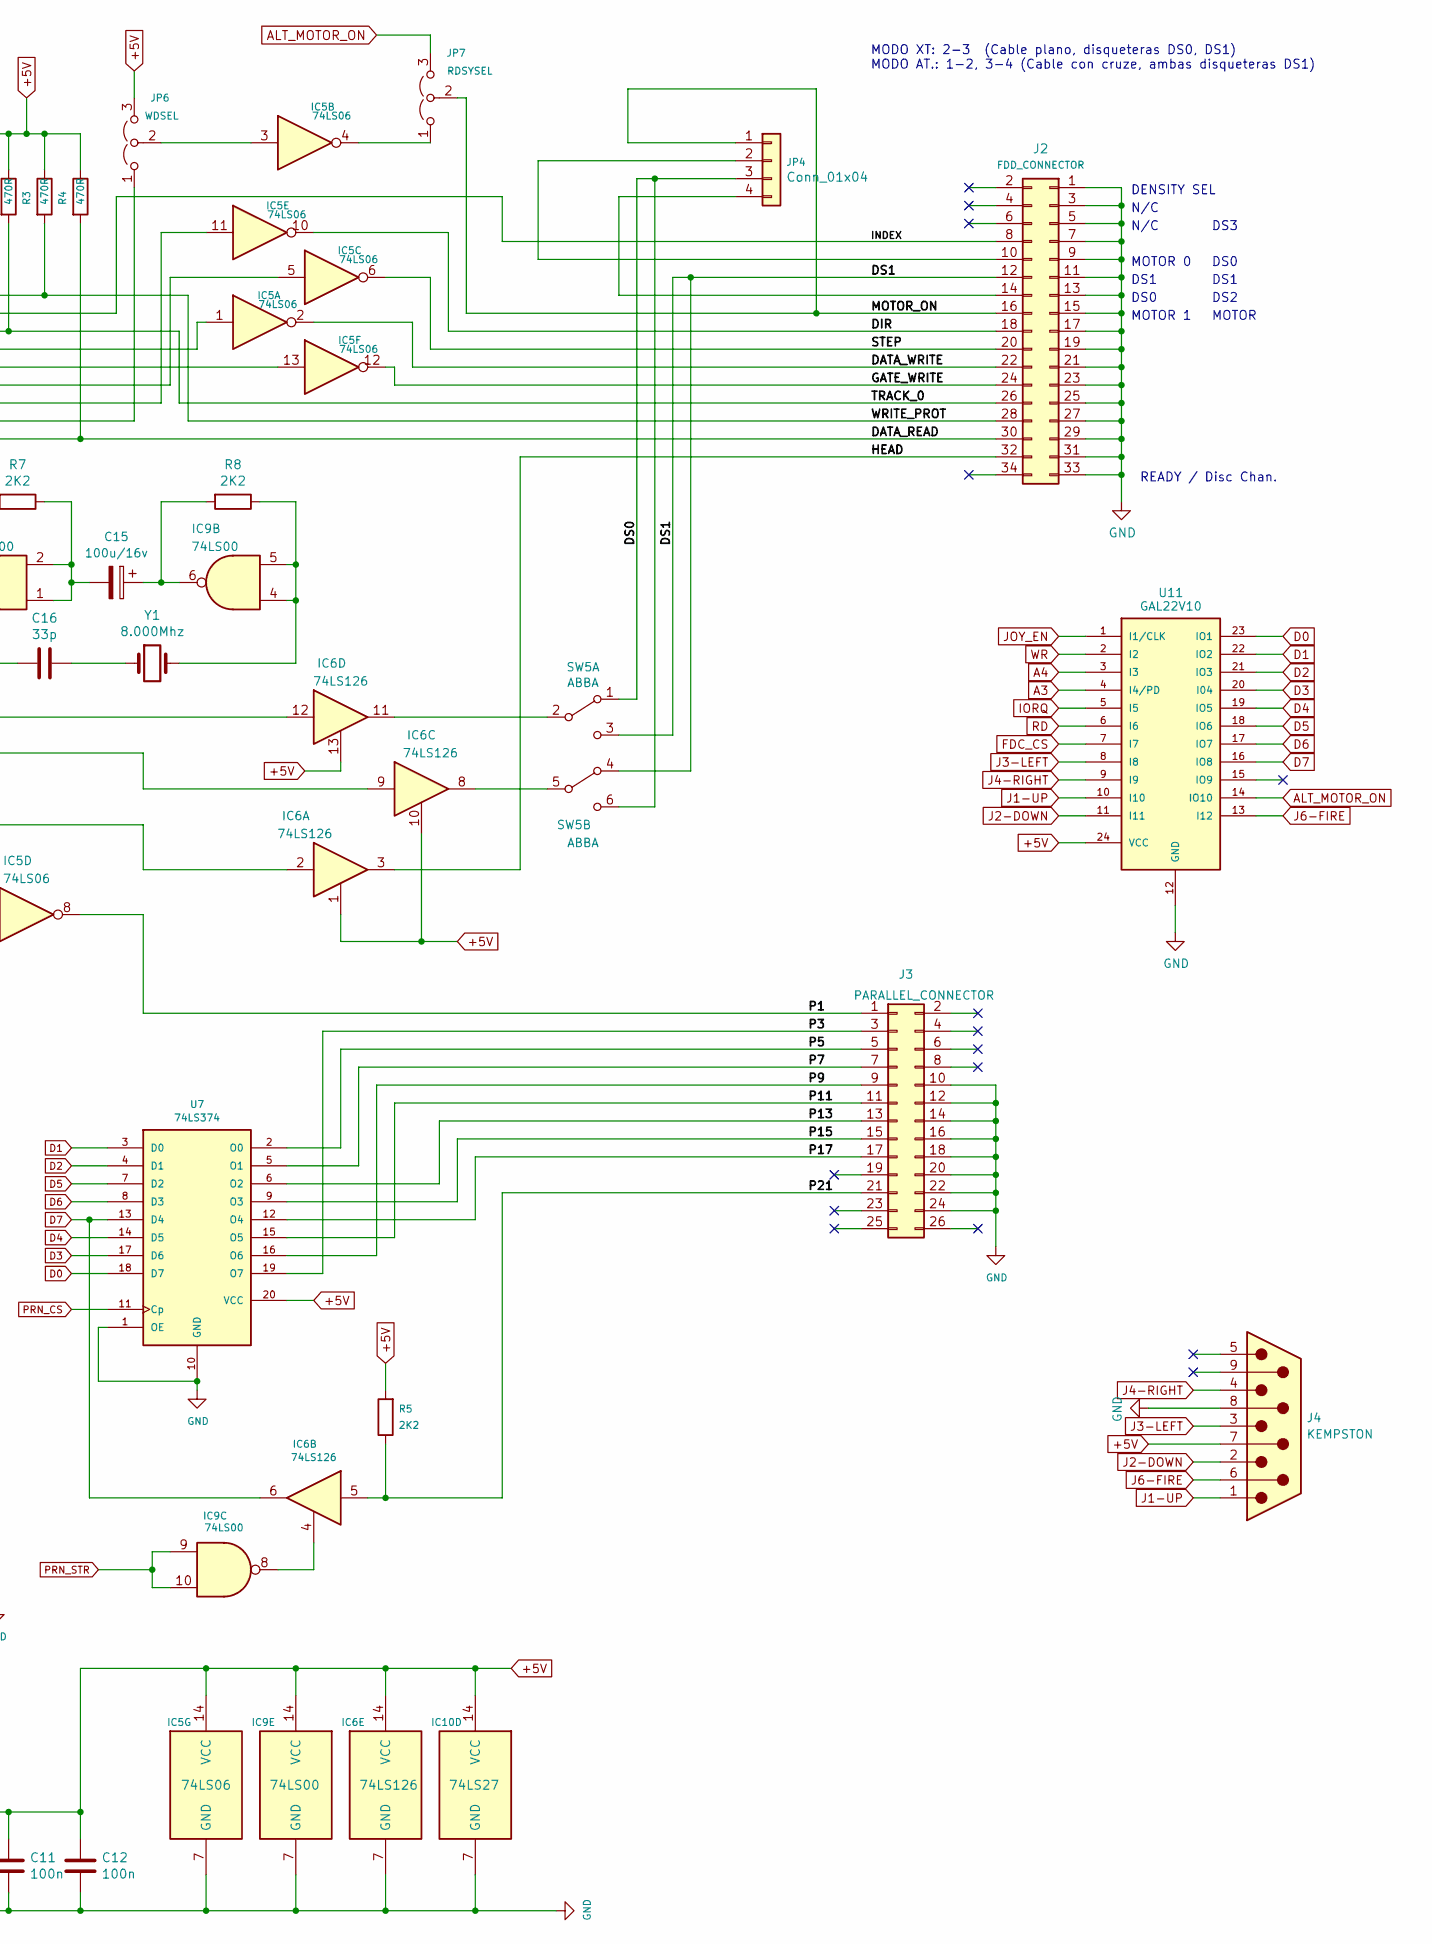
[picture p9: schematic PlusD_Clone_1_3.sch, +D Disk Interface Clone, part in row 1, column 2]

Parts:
C1, C15: 100u/16v; C_Elec_6.3x5.4
C2, C3, C4, C5, C6, C7, C8, C9, C10, C11, C12, C14: 100n; C_Disc_D5.0mm_W2.5mm_P5.00mm
C13: 100p; C_Disc_D5.0mm_W2.5mm_P5.00mm
C16: 33p; C_Disc_D5.0mm_W2.5mm_P5.00mm
D1: LD_ACT; LED_D5.0mm
D2, D3, D4: 1N4148; D_DO-35_SOD27_P7.62mm_Horizontal
D5: LD_PWR; LED_D5.0mm
IC5: 74LS06; DIP-14_W7.62mm_Socket_LongPads
IC6: 74LS126; DIP-14_W7.62mm_Socket_LongPads
IC9: 74LS00; DIP-14_W7.62mm_Socket_LongPads
IC10: 74LS27; DIP-14_W7.62mm_Socket_LongPads
J1: ZX_CONNECTOR_GENERIC_SORTED
J2: FDD_CONNECTOR; PinHeader_2x17_P2.54mm_Vertical
J3: PARALLEL_CONNECTOR; PinHeader_2x13_P2.54mm_Vertical
J4: KEMPSTON; DSUB-9_Male_Horizontal_P2.77x2.84mm_EdgePinOffset4.94mm_Hou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
JP4: Conn_01x04; PinHeader_1x04_P2.54mm_Horizontal
JP6: WDSEL; SolderJumper-3_P1.3mm_Open_RoundedPad1.0x1.5mm
JP7: RDSYSEL; SolderJumper-3_P1.3mm_Open_RoundedPad1.0x1.5mm
R1, R2, R3, R4: 470R; R_Axial_DIN0207_L6.3mm_D2.5mm_P7.62mm_Horizontal
R5, R7, R8: 2K2; R_Axial_DIN0207_L6.3mm_D2.5mm_P7.62mm_Horizontal
R6, R10: 680; R_Axial_DIN0207_L6.3mm_D2.5mm_P7.62mm_Horizontal
R9: 270; R_Axial_DIN0207_L6.3mm_D2.5mm_P7.62mm_Horizontal
R11, R12: 10K; R_Axial_DIN0207_L6.3mm_D2.5mm_P7.62mm_Horizontal
SW1: RESET; SW_PUSH_6mm
SW2: NMI; SW_PUSH_6mm
SW3: ROMSEL_JOY; SW_DIP_SPSTx03_Piano_10.8x9.18mm_W7.62mm_P2.54mm
SW4: ZX_SEL; SW_CuK_OS102011MA1QN1_SPDT_Angled
SW5: ABBA; SW_CuK_JS202011AQN_DPDT_Angled
U1: WD1772; DIP-28_W15.24mm_Socket_LongPads
U2: W27E257; DIP-28_W15.24mm_Socket_LongPads
U3: 6264; DIP-28_W15.24mm_Socket_LongPads
U4: GAL20V8B; DIP-24_W7.62mm_Socket_LongPads
U7: 74LS374; DIP-20_W7.62mm_Socket_LongPads
U8: 74LS175; DIP-16_W7.62mm_Socket_LongPads
U11: GAL22V10; DIP-24_W7.62mm_Socket_LongPads
Y1: 8.000Mhz; Crystal_HC18-U_Vertical

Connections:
+5V: C1.1, C2.2, C3.2, C4.2, C5.2, C6.2, C7.2, C8.2, C9.2, C10.2, C11.2, C12.2, IC5.14 (VCC), IC6.1, IC6.10, IC6.13, IC6.14 (VCC), IC9.14 (VCC), IC10.14 (VCC), J1.3B (+5V), J4.7, JP6.3 (B), R1.1, R2.1, R3.1, R4.1, R5.2, R6.2, R10.2, R11.2, R12.2, U1.15 (VCC), U2.28 (VCC), U3.26 (CE2), U3.28 (VCC), U4.24 (VCC), U7.20 (VCC), U8.16 (VCC), U11.24 (VCC)
/DATA_READ: J2.30, R4.2, U1.19 (~RD)
/DATA_WRITE: IC5.2, J2.22
/DIR: IC5.10, J2.18
/DS0: JP4.3, SW5.1 (A), SW5.6 (C)
/DS1: J2.12, SW5.3 (C), SW5.4 (A)
/GATE_WRITE: IC5.12, J2.24
/HEAD: IC6.3, J2.32
/INDEX: J2.8, R1.2, U1.24 (~IP)
/MOTOR_ON: J2.16, JP4.1, JP7.2 (C)
/P1: IC5.8, J3.1
/P3: J3.3, U7.19 (O7)
/P5: J3.5, U7.2 (O0)
/P7: J3.7, U7.5 (O1)
/P9: J3.9, U7.16 (O6)
/P11: J3.11, U7.15 (O5)
/P13: J3.13, U7.6 (O2)
/P15: J3.15, U7.9 (O3)
/P17: J3.17, U7.12 (O4)
/P21: IC6.5, J3.21, R5.1
/STEP: IC5.6, J2.20
/TRACK_0: J2.26, R2.2, U1.23 (~TR00)
/WDDIRC: IC5.11, U1.17 (DIRC)
/WDMOTOR: JP6.1 (A), U1.20 (MOTOR)
/WDSTEP: IC5.5, U1.16 (STEP)
/WDWD: IC5.1, U1.22 (WD)
/WDWG: IC5.13, U1.21 (WG)
/WRITE_PROT: J2.28, R3.2, U1.25 (~WPRT)
A0: IC10.9, J1.9B (A0), U2.10 (A0), U3.10 (A0)
A1: J1.10B (A1), U2.9 (A1), U3.9 (A1), U4.13 (I13)
A2: J1.11B (A2), U2.8 (A2), U3.8 (A2), U4.14 (I14)
A3: J1.12B (A3), U1.3 (A0), U2.7 (A3), U3.7 (A3), U4.11 (I11), U11.4 (I4/PD)
A4: J1.24B (A4), U1.4 (A1), U2.6 (A4), U3.6 (A4), U4.10 (I10), U11.3 (I3)
A5: J1.23B (A5), SW3.4, U2.5 (A5), U3.5 (A5), U4.9 (I9)
A6: J1.22B (A6), U2.4 (A6), U3.4 (A6), U4.8 (I8)
A7: IC10.10, J1.21B (A7), U2.3 (A7), U3.3 (A7)
A8: IC10.11, J1.26A (A8), U2.25 (A8), U3.25 (A8)
A9: IC10.13, J1.27B (A9), U2.24 (A9), U3.24 (A9)
A10: IC10.1, J1.27A (A10), U2.21 (A10), U3.21 (A10)
A11: IC10.2, J1.28B (A11), U2.23 (A11), U3.23 (A11)
A12: IC10.3, J1.2B (A12), U2.2 (A12), U3.2 (A12)
A13: J1.2A (A13), U4.3 (I3)
A14: J1.1B (A14), U4.1 (I1)
A15: J1.1A (A15), U4.2 (I2)
ALT_MOTOR_ON: JP7.3 (B), U11.14 (IO10)
D0: J1.6A (D0), U1.5 (D0), U2.11 (D0), U3.11 (D0), U7.18 (D7), U8.4 (D0), U11.23 (IO1)
D1: J1.7A (D1), U1.6 (D1), U2.12 (D1), U3.12 (D1), U7.3 (D0), U8.5 (D1), U11.22 (IO2)
D2: J1.8A (D2), U1.7 (D2), U2.13 (D2), U3.13 (D2), U7.4 (D1), U11.21 (IO3)
D3: J1.11A (D3), U1.8 (D3), U2.15 (D3), U3.15 (D3), U7.17 (D6), U11.20 (I04)
D4: J1.12A (D4), U1.9 (D4), U2.16 (D4), U3.16 (D4), U7.14 (D5), U11.19 (IO5)
D5: J1.10A (D5), U1.10 (D5), U2.17 (D5), U3.17 (D5), U7.7 (D2), U11.18 (IO6)
D6: J1.9A (D6), U1.11 (D6), U2.18 (D6), U3.18 (D6), U7.8 (D3), U8.12 (D2), U11.17 (IO7)
D7: IC6.6, J1.3A (D7), U1.12 (D7), U2.19 (D7), U3.19 (D7), U7.13 (D4), U8.13 (D3), U11.16 (IO8)
DSK_CS: U4.19 (IO19), U8.9 (Cp)
FDC_CS: U1.1 (~CS), U4.22 (IO22), U11.7 (I7)
GND: C1.2, C2.1, C3.1, C4.1, C5.1, C6.1, C7.1, C8.1, C9.1, C10.1, C11.1, C12.1, C13.1, C14.1, D5.1 (K), IC5.7 (GND), IC6.7 (GND), IC9.7 (GND), IC10.7 (GND), J1.6B (GND), J1.7B (GND), J1.14B (GND), J2.1, J2.3, J2.5, J2.7, J2.9, J2.11, J2.13, J2.15, J2.17, J2.19, J2.21, J2.23, J2.25, J2.27, J2.29, J2.31, J2.33, J3.10, J3.12, J3.14, J3.16, J3.18, J3.20, J3.22, J3.24, J4.8, SW1.2 (B), SW3.1, SW3.2, U1.14 (GND), U1.26 (~DDEN), U2.14 (GND), U3.1 (N/C), U3.14 (GND), U4.12 (GND), U7.1 (OE), U7.10 (GND), U8.8 (GND), U11.12 (GND)
IORQ: J1.17A (~IORQ), U4.5 (I5), U11.5 (I5)
J1-UP: J4.1, U11.10 (I10)
J2-DOWN: J4.2, U11.11 (I11)
J3-LEFT: J4.3, U11.8 (I8)
J4-RIGHT: J4.4, U11.9 (I9)
J6-FIRE: J4.6, U11.13 (I12)
JOY_EN: SW3.3, U11.1 (I1/CLK)
M1: IC10.4, J1.24A (~M1)
MREQ: J1.16A (~MREQ), U4.4 (I4)
NMI: J1.14A (~NMI), SW2.1 (A)
unnamed: C13.2, R9.1, U4.23 (I23)
unnamed: C15.1, IC9.6, R8.2
unnamed: C15.2, IC9.1, IC9.2, R7.1
unnamed: C16.1, Y1.1
unnamed: C16.2, IC9.3, R7.2, U1.18 (CLK)
unnamed: D1.1 (K), SW2.2 (B), SW4.2 (B), U4.21 (IO21)
unnamed: D1.2 (A), R6.1
unnamed: D2.2 (A), SW4.3 (C)
unnamed: D3.2 (A), D4.2 (A), SW4.1 (A)
unnamed: D5.2 (A), R10.1
unnamed: IC5.3, JP6.2 (C)
unnamed: IC5.4, JP7.1 (A)
unnamed: IC5.9, U8.10 (Q2)
unnamed: IC6.2, U8.14 (~Q3)
unnamed: IC6.4, IC9.8
unnamed: IC6.8, SW5.5 (B)
unnamed: IC6.9, U8.6 (~Q1)
unnamed: IC6.11, SW5.2 (B)
unnamed: IC6.12, U8.3 (~Q0)
unnamed: IC9.4, IC9.5, R8.1, Y1.2
unnamed: IC9.11, IC10.5
unnamed: IC10.6, R9.2
unnamed: IC9.13, IC10.8
unnamed: IC9.12, IC10.12
unnamed: J2.10, JP4.2
unnamed: J2.14, JP4.4
PRN_CS: U4.18 (IO18), U7.11 (Cp)
PRN_STR: IC9.9, IC9.10, U4.20 (I020)
RAM_CS: U3.20 (~CE1), U4.16 (IO16)
RD: J1.18A (~RD), U2.22 (~OE), U3.22 (~OE), U4.6 (I6), U11.6 (I6)
RESET: C14.2, J1.20B (~RESET), SW1.1 (A), U1.13 (~MR), U8.1 (~Mr)
ROM48: D2.1 (K), J1.25B (~ROMCS)
ROMA13: R12.1, SW3.5, U2.26 (A13)
ROMA14: R11.1, SW3.6, U2.27 (A14)
ROMOE1: D4.1 (K), J1.4A (NC_ROM1OE)
ROMOE2: D3.1 (K), J1.15B (VIDEO_ROM2OE)
ROM_CS: U2.20 (~CE), U4.15 (IO15)
WR: J1.19A (~WR), U1.2 (R/~W), U3.27 (~WR), U4.7 (I7), U11.2 (I2)

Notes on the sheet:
READY / Disc Chan.
DENSITY SEL
N/C
MOTOR 1
DS0
DS1
MOTOR 0
MOTOR
DS2
DS0
DS3
MODO XT: 2-3 (Cable plano, disqueteras DS0, DS1) MODO AT.: 1-2, 3-4 (Cable con cruze, ambas disqueteras DS1)

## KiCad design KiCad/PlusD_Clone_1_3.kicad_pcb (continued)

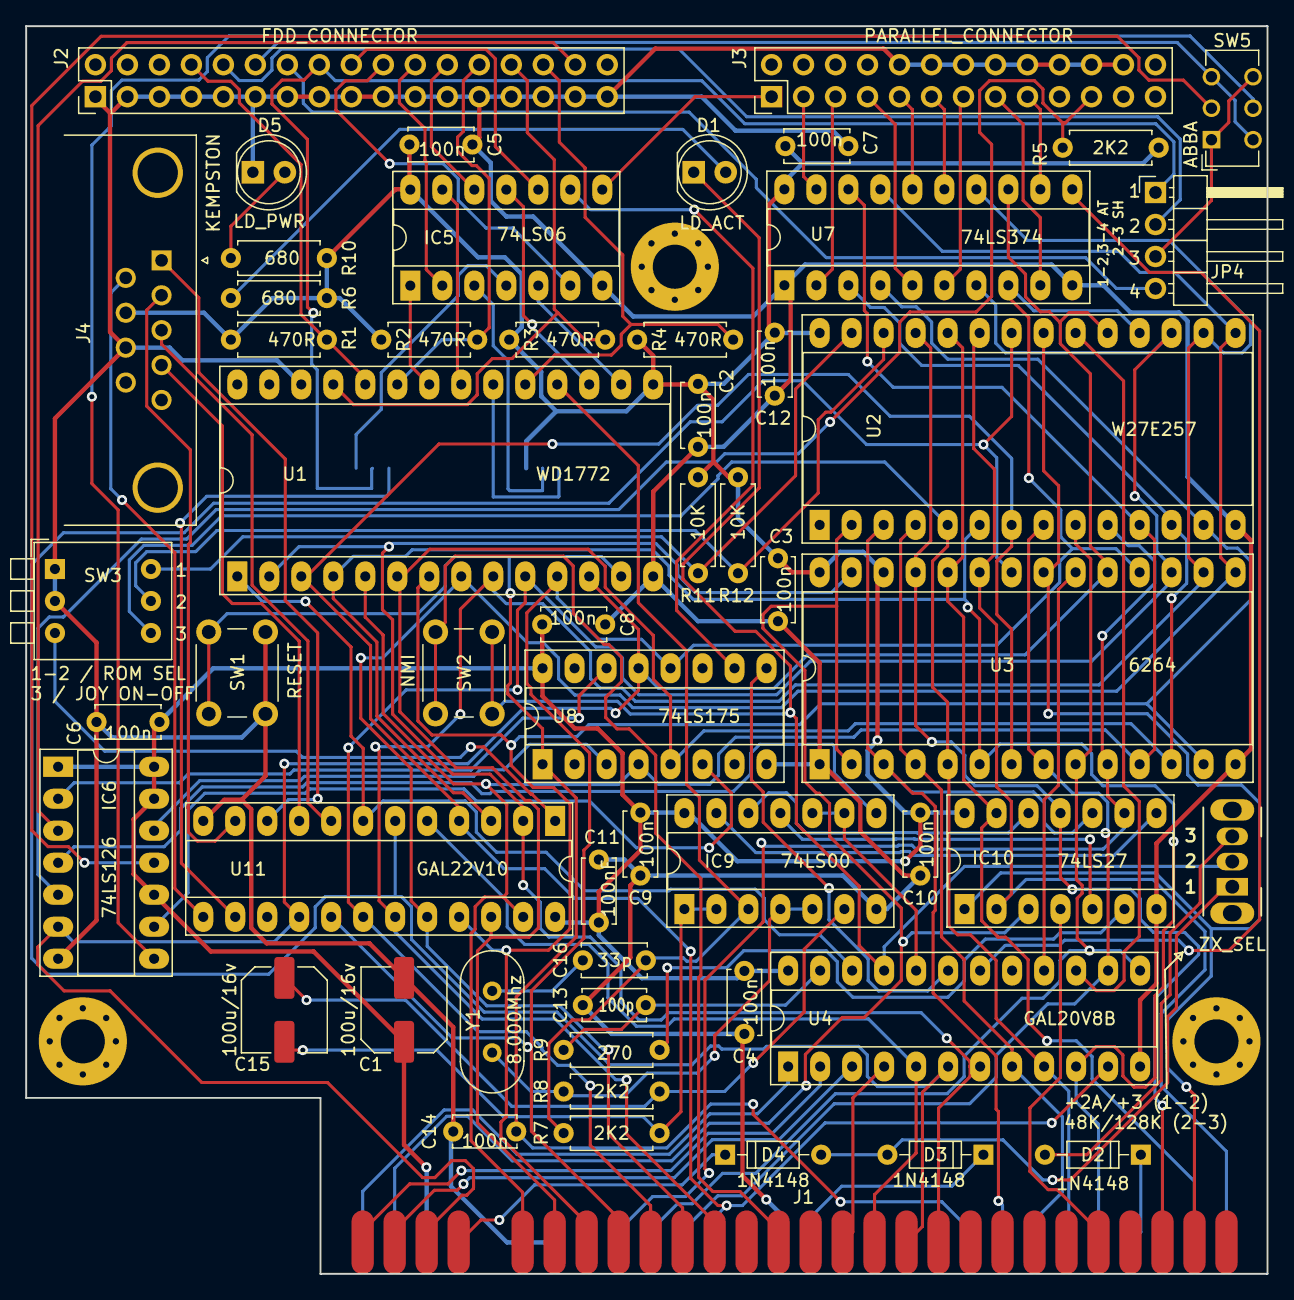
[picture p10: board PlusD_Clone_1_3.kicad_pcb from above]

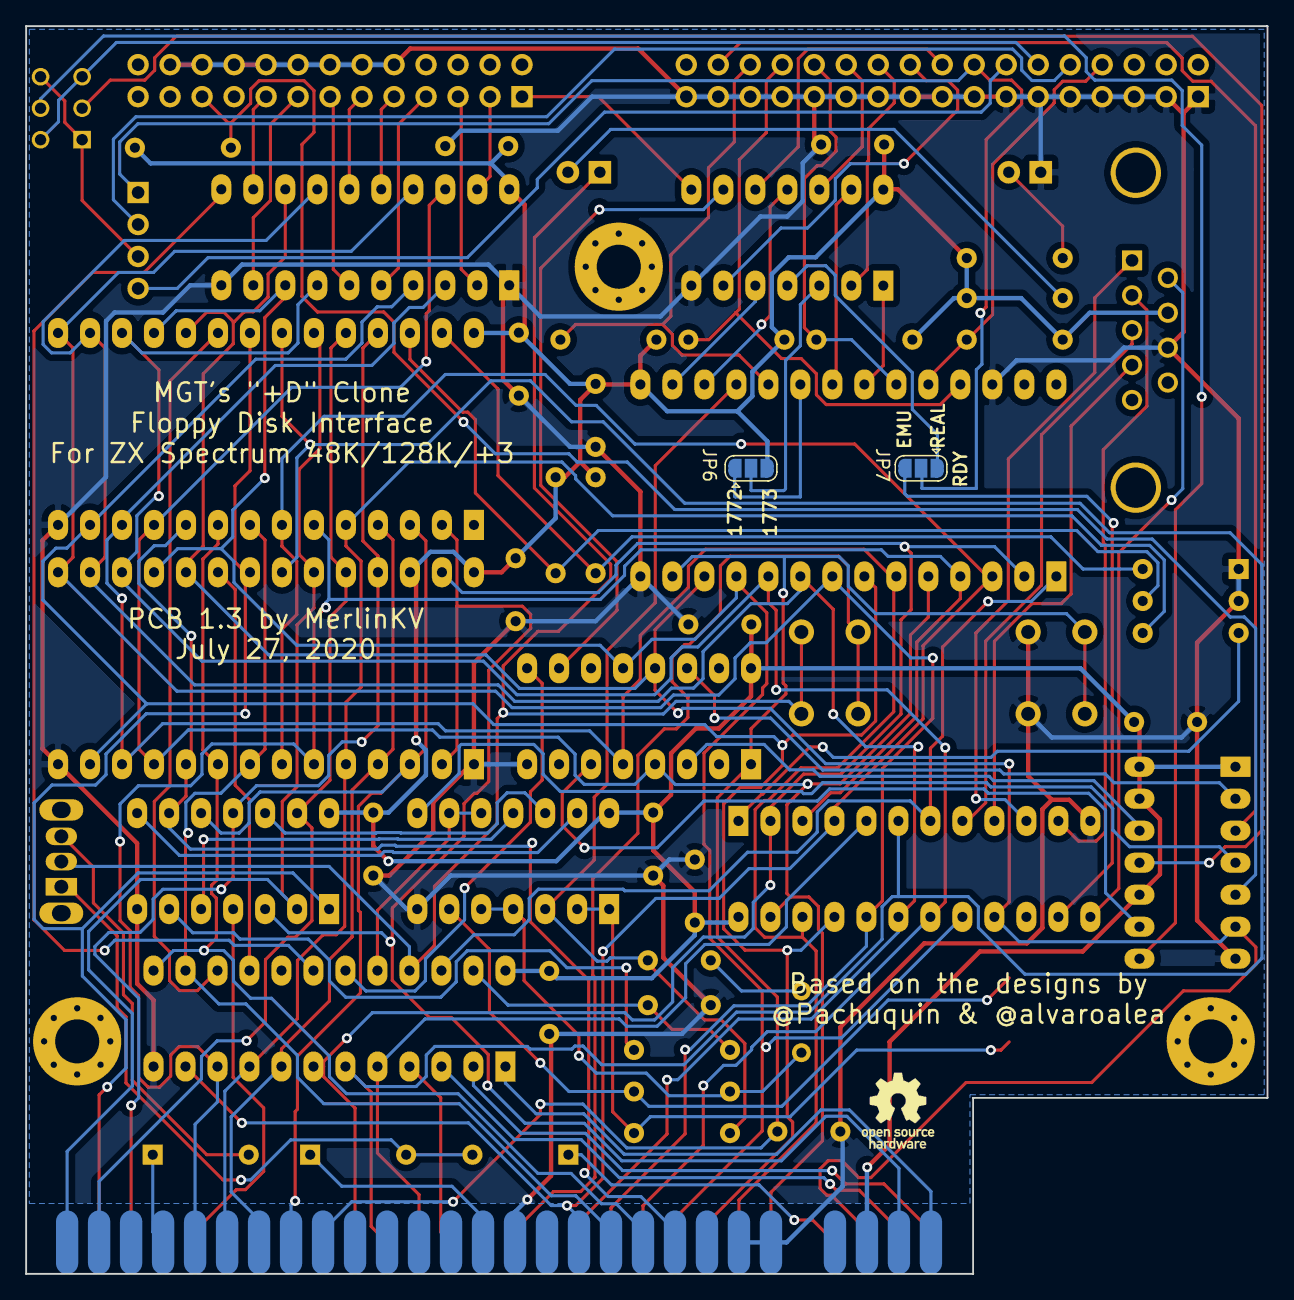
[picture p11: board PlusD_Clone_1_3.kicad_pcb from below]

Board: 2 copper layers, 98.6 x 99.1 mm, 61 parts (3 on the bottom side), 104 nets.

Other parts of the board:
HOLE1, HOLE2, HOLE3: MountingHole_3.5mm_Pad_Via
LOGO1: OSHW-Logo_5.7x6mm_SilkScreen
